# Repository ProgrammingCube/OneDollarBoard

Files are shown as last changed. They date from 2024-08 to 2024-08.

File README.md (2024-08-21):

# One Dollar Board

## What is it?
This ATtiny85 board is a bit different than most. In fact, it is a spiritual successor to the [One Dollar Board](https://www.indiegogo.com/projects/one-dollar-board--5/x/14830965#/updates/all) Indiegogo project from 2016. This campaign made more than its goal and failed to deliver. Now, I am much more experienced than I was then. This project is my attempt to bring its idea to fruition.

While I have no where the buisness connections to create a true $1 board, this kit is something you can [buy]() or print yourself!

## Build process

Watch the video (https://youtu.be/vt5fpE0bzSY)

This video will help you through the build process of the board. If you wish to have a writeup, [this]() is a link to the build how-to PDF. Those who purchase this kit will have also have a physical manual.

## Arduino IDE Setup
[Download Arduino IDE](https://www.arduino.cc/en/software)

In order to use this board seamlessly with the Arduino IDE, you need to install the Digispark Boards. These boards seem to be discontinued, but the json file is still extant.

Simply go to `File >> Preferencess` and click on the `Additional Boards Manager URLs` to add this entry:

`https://raw.githubusercontent.com/digistump/arduino-boards-index/master/package_digistump_index.json`

Click on OK.

Then, go `Tools >> Board... >> Boards Manager`. From here, search `Digistump`. Install the Digistump AVR Boards package. Accept any driver installs, we need these to talk to the boards because we are using a special bootloader.

#### Special note on the Bootloader***
Your ATtiny85 comes with a bootloader preinstalled, the [Micronucleus](https://github.com/SpenceKonde/ATTinyCore/blob/v2.0.0-devThis-is-the-head-submit-PRs-against-this/avr/extras/Ref_Micronucleus.md) bootloader. This allows one to program the chip via USB instead of using a middle-man ISP. You can still use an ISP if you want though, and its easy enough to flash back to the Micronucleus bootloader.

Here is the [link](https://github.com/ashishchoudhary9998/ATtiny85-Boot-loader) for the Micronucleus bootloader I have used. You can use a different one if you want, or if you're good enough, you can [make your own](https://ww1.microchip.com/downloads/aemDocuments/documents/MCU08/ApplicationNotes/ApplicationNotes/Basic-Bootloader-for-AVR-MCU-DA-Family-DS00003341C.pdf) or even [write it in C](https://github.com/m3y54m/simple-avr-bootloader) !

Once you have the board installed, select the correct board by doing `Tools >> Boards... >> Digistump AVR Boards >> Digispark (Default, 16.5mhz)`. Then select `Tools >> Programmer >> Micronucleus`.
**IF YOU CAN'T UPLOAD CODE AND YOU GET A MESSAGE WITH ONLY 60% UPLOADED, CHECK YOUR PROGRAMMER SELECTION** For some reason, Arduino IDE likes to deselect this.

## Microchip Studio Setup
[Download Microchip Studio](https://www.microchip.com/en-us/tools-resources/develop/microchip-studio#Downloads)

Setup is a bit more nuanced, and it can be a bit more difficult if your computer setup is different. However, the setup is almost the same!

Refer to the **Arduino IDE Setup** section and follow the guide to install the board in the Boards Manager. From there, we pick up.

To start a new project, you need to select what language you will use. From there, you need to add an `External Tool`.

`External Tools` is a fantastic feature in which you can run user-arbitrary executables with whatever command line options you want. Most uses exercise this feature to add custom binary upload programs to the IDE, making a seamless environment from code, compile, to upload.

Here's what to do. Go to `Tools >> External Tools...`. From there, click `Add`. Name the tool something meaningful, like `ATtiny85_VUSB` or `ATtiny85_Micronucleus` or something like that.

Next, we will fill out the `Command` field. This will specify which .exe to run when the External Tool is selected. For us, we need to use the `launcher.exe` supplied by the Arduino board install.

In order to find this tool, go to the Arduino IDE, go to `File >> Preferences` and enable `Show verbose output during` for `upload`. Then, select the Digistump board as in the **Arduino IDE Setup**, and build/upload a blank sketch to your ATtiny85 board.

In the `Output` window, you should see something like this:

`C:\Users\yourusername\AppData\Local\Arduino15\packages\digistump\tools\micronucleus\2.0a4/launcher.exe`

or wherever you have installed Arduino IDE. Copy this text to the `Command` field in the `External Tools...` window.

Next, you can copy this text directly to the `Arguments` field:

`-cdigispark --timeout 60 -Uflash:w:"$(TargetName)\$(TargetName)\Debug\$(TargetName).hex":i`

The variables `$(TargetNamee)` are used so the default .hex file will be uploaded, regardless of what the source file is named.

Next, we need to change the `Initial Directory` field. This directory will be the `Atmel Studio/7.0` folder's location like this:

`C:\Users\yourusername\Documents\Atmel Studio\7.0`

There's a strange bug in Microchip Studio in which spaces in the directory aren't handled right, so we'll do this to avoid problems.

Perfect! Now, when you use Microchip Studio, you can press `F7` to compile/assemble your program, then use `Tools >> your-external-tool` to upload! If you're good, you can [keybind your tool](https://onlinedocs.microchip.com/pr/GUID-ECD8A826-B1DA-44FC-BE0B-5A53418A47BD-en-US-12/index.html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)!
# FAQ
### The PWR LED doesn’t turn on!!!
- Check to make sure the power LED is installed the right way round. The molded flat plastic should be facing USER RIGHT.
- Double-check your USB connector solder joints. This LED is a direct power to ground connection, so if this doesn’t turn on, something simple is wrong.
- If your computer pops a message saying Overcurrent Detection, you may have a short in the upper-left quadrant of your board, or a short on the ATtiny85 IC socket. Ensure that all solder joints are isolated.
### The PB0 LED doesn’t blink!!!1!
Unfortunately, there can be many causes for this problem.
- Check if the LEDs are installed the right way round. The molded flat plastic should be facing USER RIGHT.
- Be sure that the ATtiny85 is installed correctly. Its index notch should be facing USER LEFT. Also, make sure its pins aren’t bent or sticking out from the socket.
- Double-check your soldering of the ATtiny85 IC socket. You wouldn’t believe how many times veteran hobbyists forget to solder entire chips!
### When I start using the other chips, nothing works!
- Check to see if there are shorts on the IC sockets.
- Check if the LD117V33 regulator is installed correctly. Refer to the images.
- Be careful on where you plug power and data cables. By design, this board is EXTREMELY flexible. I have tried to do my best to make the silkscreen clear, but it is still possible to accidentally switch around power and data pins. Refer to the pinout diagrams.

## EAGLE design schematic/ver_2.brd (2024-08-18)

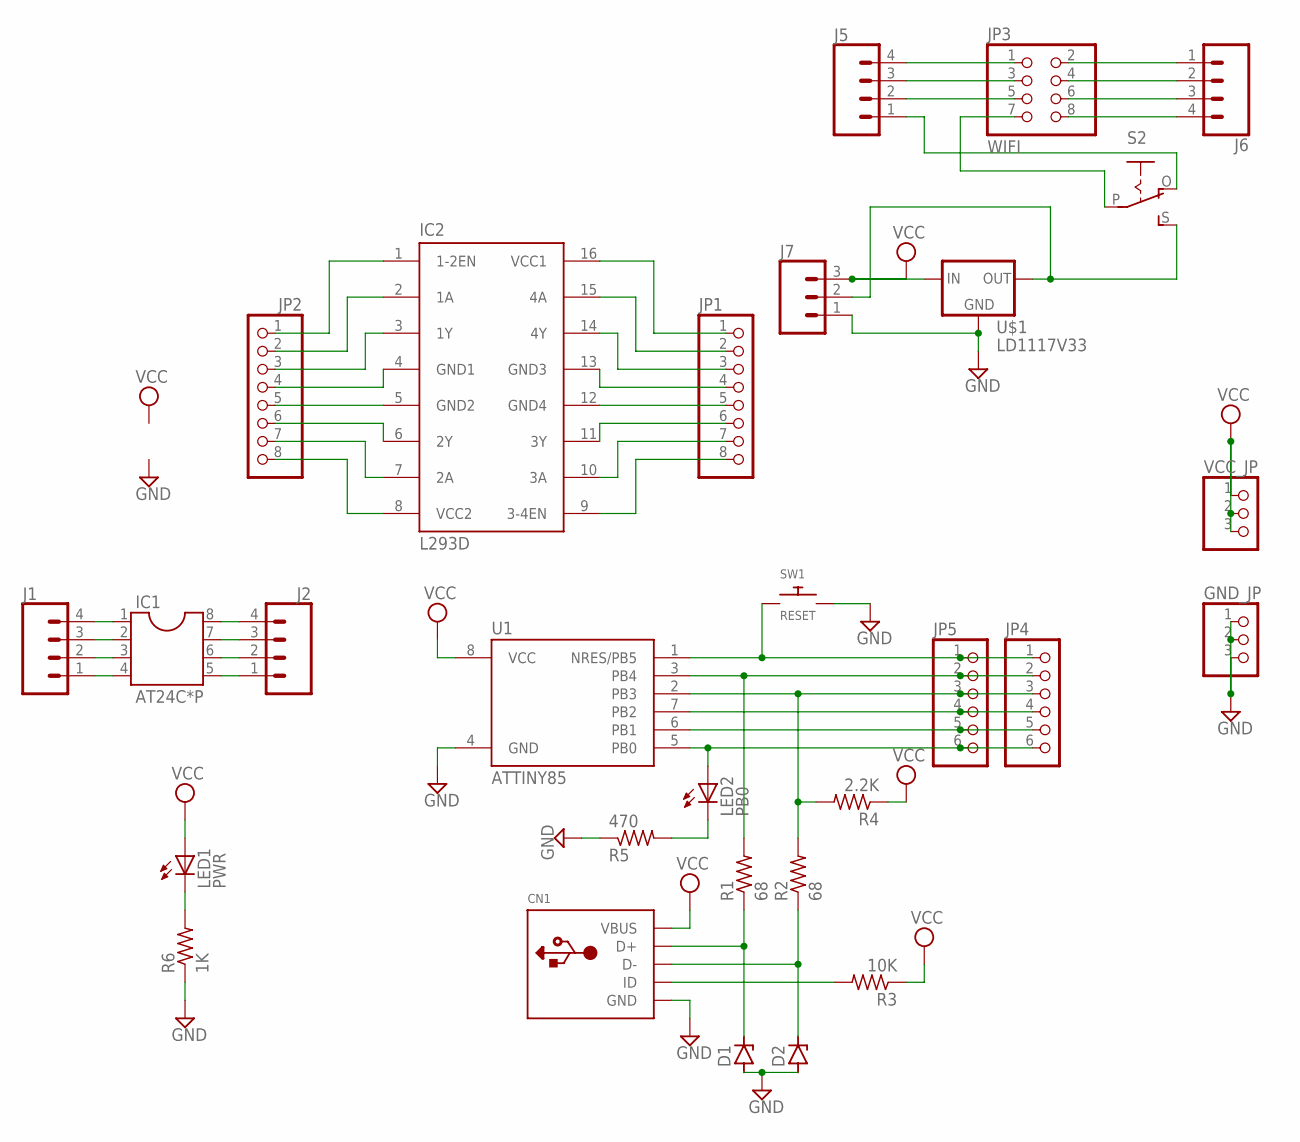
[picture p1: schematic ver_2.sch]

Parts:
CN1: USBTHM; USB-MINIB-THM
D1, D2: ZENER-DIODEDO34-7; DO34Z7
GND_JP: PINHD-1X3; 1X03
IC1: AT24C*P; SOCKET-08
IC2: L293D; DIL16
J1, J2: CONN_041X04_NO_SILK; 1X04_NO_SILK
J5, J6: CONN_04PTH; 1X04
J7: CONN_03; 1X03
JP1, JP2: PINHD-1X8CLEANBIG; 1X08-CLEANBIG
JP3: WIFI; 2X04
JP4, JP5: PINHD-1X6; 1X06
LED1: PWR; LED3MM
LED2: PB0; LED3MM
R1, R2: 68; 0204V
R3: 10K; 0204V
R4: 2.2K; 0204V
R5: 470; 0204V
R6: 1K; 0204V
S2: EG1218S; EG1218
SW1: RESET; TACT_PANA-EVQ
U1: ATTINY85; PDIP08_300MIL
U$1: LD1117V33
VCC_JP: PINHD-1X3; 1X03

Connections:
GND: CN1.GND, D1.A, D2.A, GND_JP.1, GND_JP.2, GND_JP.3, J7.1, R5.1, R6.1, SW1.P$2, U1.4 (GND), U$1.GND
unnamed: JP4.1, JP5.1, SW1.P$1, U1.1 (NRES/PB5)
unnamed: JP4.2, JP5.2, R1.2, U1.3 (PB4)
unnamed: JP4.3, JP5.3, R2.2, R4.2, U1.2 (PB3)
unnamed: JP4.4, JP5.4, U1.7 (PB2)
unnamed: JP4.5, JP5.5, U1.6 (PB1)
unnamed: JP4.6, JP5.6, LED2.A, U1.5 (PB0)
unnamed: IC1.4, J1.1
unnamed: IC1.3, J1.2
unnamed: IC1.2, J1.3
unnamed: IC1.1, J1.4
unnamed: IC1.5, J2.1
unnamed: IC1.6, J2.2
unnamed: IC1.7, J2.3
unnamed: IC1.8, J2.4
unnamed: CN1.ID, R3.2
unnamed: IC2.4 (GND1), JP2.4
unnamed: CN1.D+, D1.C, R1.1
unnamed: CN1.D-, D2.C, R2.1
unnamed: IC2.5 (GND2), JP2.5
unnamed: IC2.6 (2Y), JP2.6
unnamed: IC2.7 (2A), JP2.7
unnamed: IC2.8 (VCC2), JP2.8
unnamed: IC2.3 (1Y), JP2.3
unnamed: IC2.2 (1A), JP2.2
unnamed: IC2.1 (1-2EN), JP2.1
unnamed: J6.3, JP3.6
unnamed: J6.2, JP3.4
unnamed: JP3.7, S2.P
unnamed: J5.2, JP3.5
unnamed: J5.3, JP3.3
unnamed: J5.4, JP3.1
unnamed: J6.4, JP3.8
unnamed: J7.2, S2.S, U$1.OUT
unnamed: J6.1, JP3.2
unnamed: IC2.12 (GND4), JP1.5
unnamed: IC2.11 (3Y), JP1.6
unnamed: IC2.10 (3A), JP1.7
unnamed: IC2.9 (3-4EN), JP1.8
unnamed: IC2.13 (GND3), JP1.4
unnamed: IC2.14 (4Y), JP1.3
unnamed: IC2.15 (4A), JP1.2
unnamed: IC2.16 (VCC1), JP1.1
unnamed: LED2.K (C), R5.2
unnamed: LED1.K (C), R6.2
unnamed: J5.1, S2.O
VCC: CN1.VBUS, J7.3, LED1.A, R3.1, R4.1, U1.8 (VCC), U$1.IN, VCC_JP.1, VCC_JP.2, VCC_JP.3

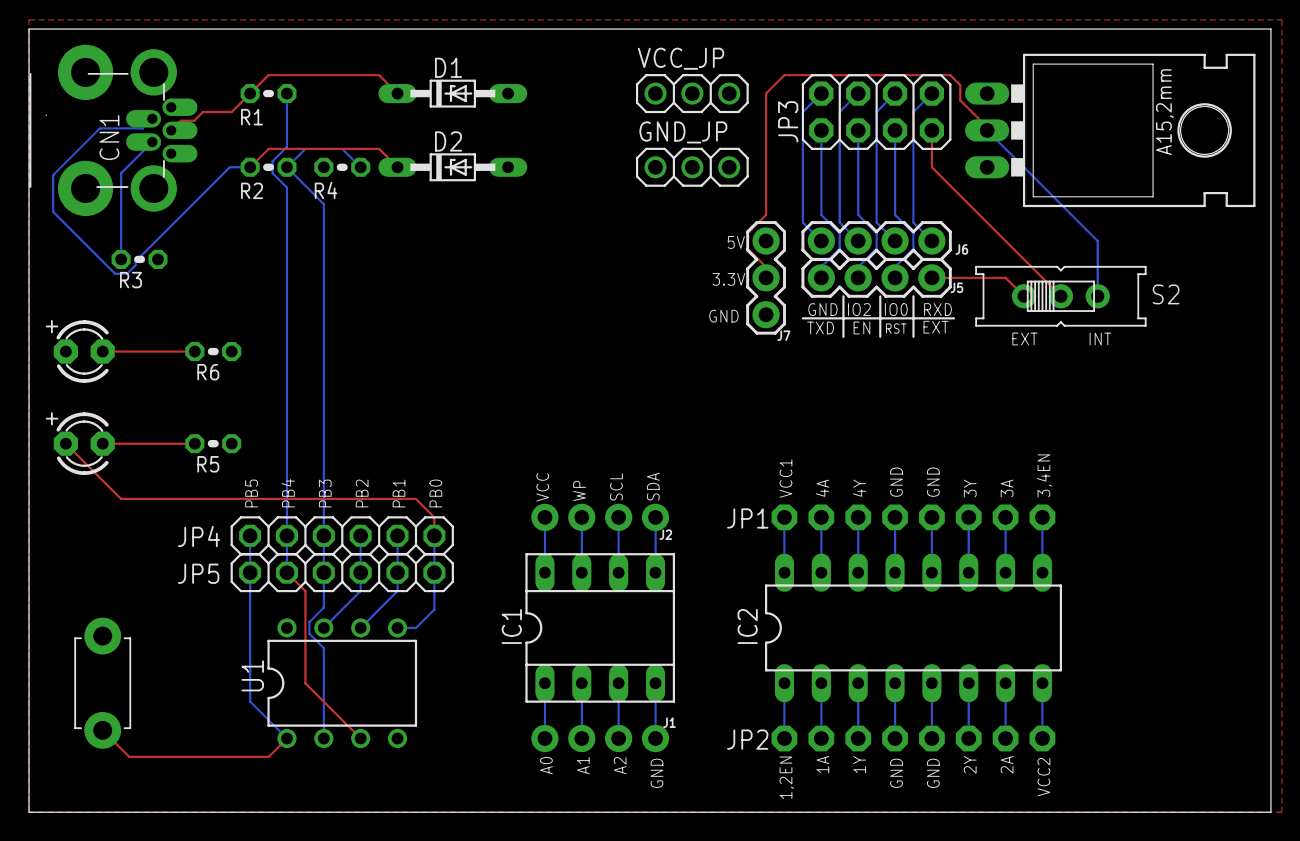
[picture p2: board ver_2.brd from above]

Board: 2 copper layers, 85.6 x 54.0 mm, 29 parts (0 on the bottom side), 47 nets.

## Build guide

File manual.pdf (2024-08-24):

# One Dollar Board

### Standalone ATtiny85 Development Kit

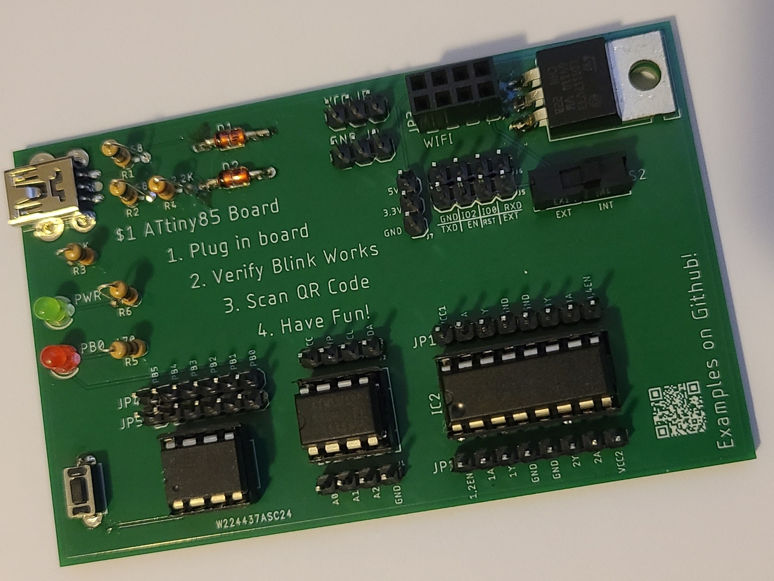
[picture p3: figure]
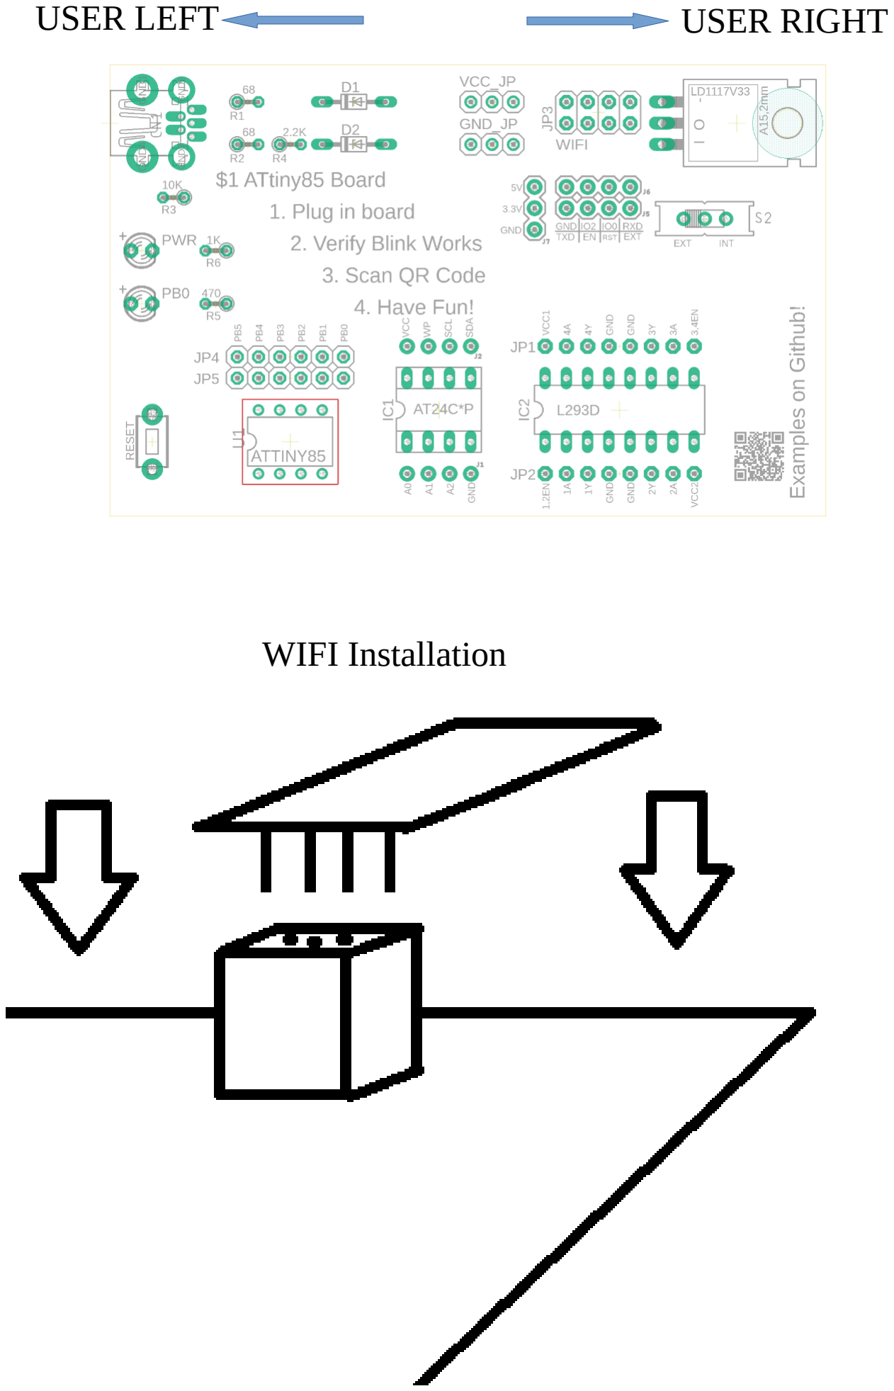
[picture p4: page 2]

USER LEFT | USER RIGHT

WIFI Installation

## Bill of Materials

(1) PCB
(2) 8 pin IC socket
(1) 16 pin IC socket
(1) ATtiny85
(1) AT24C16D
(1) L293D
(1) Red LED
(1) Green LED
(1) USB Micro Female
(2) 3.6v Zener diode
(1) LD117V33
(1) Push Button Switch
(1) 3 Pole Slide Switch
(2) 2.54 Header Male
(1) 2.54 2x4 Header Female
(2) 68 ohm Resistor
(1) 2.2 kohm Resistor
(1) 1 kohm Resistor
(1) 10 kohm Resistor
(1) 470 kohm Resistor

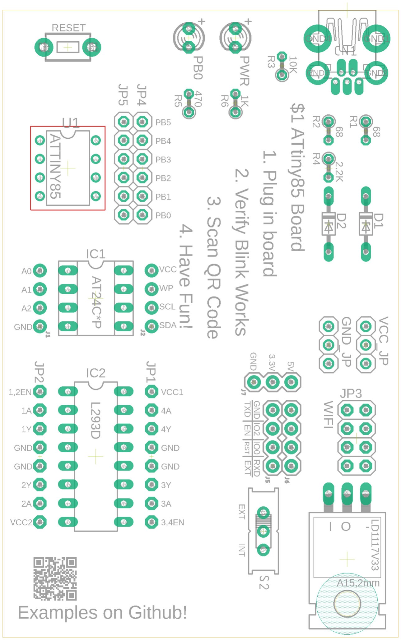
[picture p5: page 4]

This kit requires basic soldering skills and equipment!

### 1. Start by soldering in the three (3) IC sockets. Be sure to have

the index notch pointed USER LEFT!! I find the easiest way to solder these is to place them on the board, then flip the board over. Solder one (1) corner pin on each socket. Next, holding the board with your non-soldering iron hand, place your index finger (AVOID THE CORNER PIN AREA) on each socket one at a time while heating up that socket's soldered pin slightly. This will align the socket just right. Finish this step by flipping the board upside down again and finish off the soldering for the sockets.

### 2. Solder the resistors. To install these, take one lead and bend it

around until it is pointing the same direction as the other lead, like a lowercase 'n'. There is no wrong way to install these resistors, as they have no polarity. However, I do like to install the resistors with the resistor package resting on the circle of its silkscreen.

### 3. Bend and install the Zener diodes. To do this, use your

thumbnail and index finger to bend the leads about 3mm out from the package and down into a right angle. You should not be bending the leads right up against the package, or you will find installation difficult.

### 4. Install the power and GPIO LEDs. Take careful note of the

leads. The longer lead is the positive lead, and the negative side of the LED will also be molded slightly flat like the silkscreen shows. Keep in mind that LEDs are fairly delicate, so do not linger on a lead for more than 2 seconds with the iron.

### 5. Install the voltage regulator. I find that by taking a small pair

of needle nose pliers, one can bend the leads around 45-50 degrees to the component package. Then, you can easily slide the regulator into its holes. Look at the finished board picture for a visual. Line up the screw hole with the hole in the PCB before soldering in.

### 6. Solder in the headers. I find that the easiest way to do this is

similar to the sockets. Solder one end pin of a header into place, then use your index finger to press the header flush against the board as you reheat the solder joint. Once aligned, go back and solder the rest of the header pins.

### 7. Solder in the switches. The RESET switch should snap in place

and you can even solder this component without flipping the board over. Soldering the 2 position switch should be like the headers; solder one pin, press to align, and reheat the joint.

### 8. Install the micro-USB port. Place this gently on the footprint

and fill one of the four (4) ground contacts with solder. You will now be able to flip the board around and finish the soldering of this component. Keep in mind that the data pins will barely poke through the circuit board when aligned properly. Finish soldering the three (3) ground contacts.

Install the chips!
Slightly bend the package pins of the ICs inward to perpendicular with the surface of the package. I do this by taking the chip on its side and gently pressing it against a table or book. Be sure the index notch is facing USER LEFT when the chip is installed into its socket. Be sure no pins are being bent or twisted, go slow!

Plug in the board. The onboard micronucleus firmware should start the bootloader, and after 8 seconds the pin 0 LED should blink!

Let’s head over to the Git to set up your drivers and IDE!

https://github.com/ProgrammingCube/OneDollarBoard

Powering the ESP-01 Wifi Board

The slide switch on the board next to the ESP module controls where the power comes from. Because the wifi module is powered by 3.3 volts instead of the USB 5 volts, you can slide the switch to the RIGHT, to the INT position. This uses the on-board voltage regulator to power the board.
If you have the switch slid to the LEFT, to the EXT position, power will be taken in by the EXT pin on the header. You will need to supply your own power into the board. This is handy if you are taxing your USB power supply.

RESET Circuit

The RESET circuit is extremely simple on this board. The RESET push button switch simply pulls PB0 of the ATtiny85 down to GND. There is no debounce nor a pulldown/pullup. If you search other schematics, like the Digispark board, there is a pullup to power on the reset line. I have found that a board this simple does not need a pullup.
When pressed, the Micronucleus bootloader will enter the bootloader for 8 seconds. In this state, it can respond to data on the USB connected lines. This is when you need to upload your code. By using the launcher.exe provided by the Arduino board library, you will be prompted to plug in your board during upload. It is at this time you should press the RESET button, as it is much simpler than unplugging/replugging your board.
The RESET pin is not connected to any other chip on this board.

ISP (In System Programming)

If you need to reflash the Micronucleus bootloader or desire to use an ISP, you can use an Arduino as an ISP!

Disconnect the USB from the ATtiny85 board. You will now power this board from an Arduino Uno or equivalent. Please connect the pins like so:

Arduino--> ATtiny85

5V | Vcc
GND | GND
Pin 13 | PB2
Pin 12 | PB1
Pin 11 | PB0
Pin 10 | PB5/Reset
From here, use the Arduino IDE to flash the ArduinoISP sketch to your Arduino. From here, connect an electrolytic capacitor (10-22uF) between GND and RESET. This prevents the ArduinoISP device from resetting before it can write code to your ATtiny95 board.
From here, choose the Digistump 16.5mhz default board option as the target, and instead of uploading code via the normal Upload button, you need to choose Ctrl-Shift-U or Sketch >> Upload Using Programmer… You need to also have the ArduinoISP programmer selected under Tools >> Programmer. Make sure your COM port is also selected correctly to your Arduino.

Using an ISP instead of the Micronucleus bootloader will allow you to use the full 8192 bytes of flash memory, instead of the Micronucleus’s ~6.3kb.

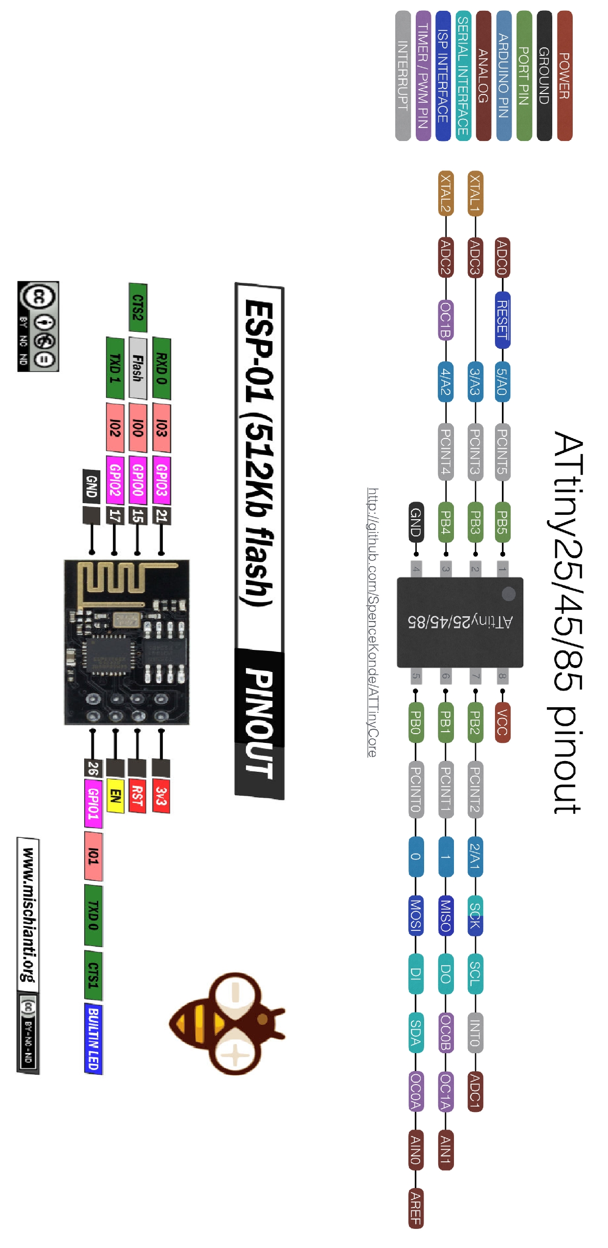
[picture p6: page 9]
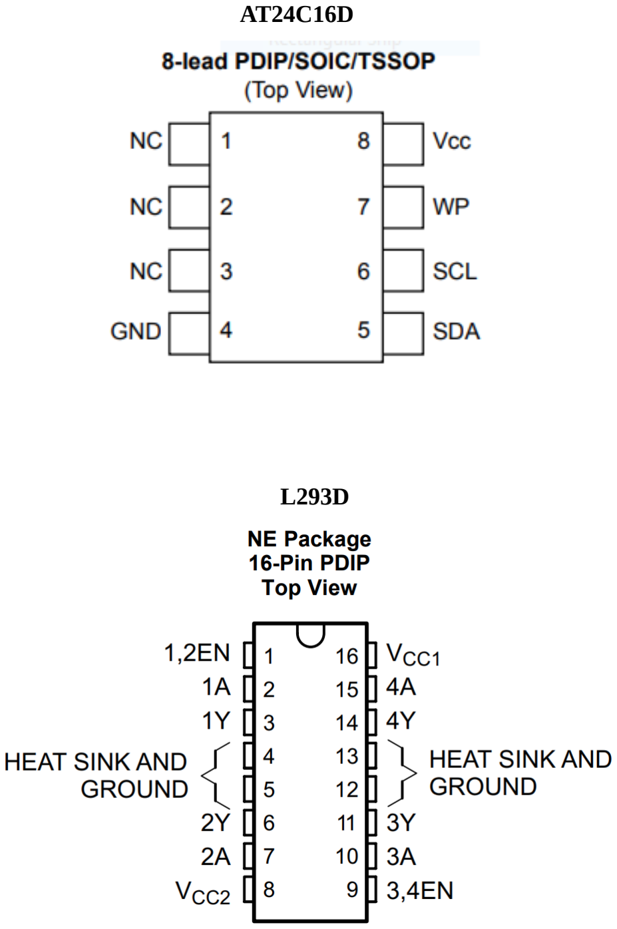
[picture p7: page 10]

AT24C16D

L293D

## FAQ

-The PWR LED doesn’t turn on!!!
- Check to make sure the power LED is installed the right way round. The molded flat plastic should be facing USER RIGHT.
- Double-check your USB connector solder joints. This LED is a direct power to ground connection, so if this doesn’t turn on, something simple is wrong.
- If your computer pops a message saying Overcurrent Detection, you may have a short in the upper-left quadrant of your board, or a short on the ATtiny85 IC socket. Ensure that all solder joints are isolated.

-The PB0 LED doesn’t blink!!!1!
Unfortunately, there can be many causes for this problem.
- Check if the LEDs are installed the right way round. The molded flat plastic should be facing USER RIGHT.
- Be sure that the ATtiny85 is installed correctly. Its index notch should be facing USER LEFT. Also, make sure its pins aren’t bent or sticking out from the socket.
- Double-check your soldering of the ATtiny85 IC socket. You wouldn’t believe how many times veteran hobbyists forget to solder entire chips!

-When I start using the other chips, nothing works!
- Check to see if there are shorts on the IC sockets.
- Check if the LD117V33 regulator is installed correctly. Refer to the images.
- Be careful on where you plug power and data cables. By design, this board is EXTREMELY flexible. I have tried to do my best to make the silkscreen clear, but it is still possible to accidentally switch around power and data pins. Refer to the pinout diagrams.

Patrick Jackson
2024

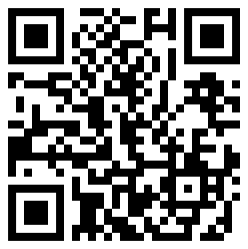
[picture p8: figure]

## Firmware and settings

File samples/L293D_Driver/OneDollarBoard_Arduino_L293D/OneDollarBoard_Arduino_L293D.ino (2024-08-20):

//L293D
//Motor A
const int motorPin1  = 0;  // Pin 14 of L293
const int motorPin2  = 1;  // Pin 10 of L293
//Motor B
const int motorPin3  = 2; // Pin  7 of L293
const int motorPin4  = 3;  // Pin  2 of L293

//This will run only one time.
void setup()
{
    //Set pins as outputs
    pinMode(motorPin1, OUTPUT);
    pinMode(motorPin2, OUTPUT);
    pinMode(motorPin3, OUTPUT);
    pinMode(motorPin4, OUTPUT);
    
    //Motor Control - Motor A: motorPin1,motorpin2 & Motor B: motorpin3,motorpin4

    //This code  will turn Motor A clockwise for 2 sec.
    digitalWrite(motorPin1, HIGH);
    digitalWrite(motorPin2, LOW);
    digitalWrite(motorPin3, LOW);
    digitalWrite(motorPin4, LOW);
    delay(2000); 
    //This code will turn Motor A counter-clockwise for 2 sec.
    digitalWrite(motorPin1, LOW);
    digitalWrite(motorPin2, HIGH);
    digitalWrite(motorPin3, LOW);
    digitalWrite(motorPin4, LOW);
    delay(2000);
    
    //This code will turn Motor B clockwise for 2 sec.
    digitalWrite(motorPin1, LOW);
    digitalWrite(motorPin2, LOW);
    digitalWrite(motorPin3, HIGH);
    digitalWrite(motorPin4, LOW);
    delay(2000); 
    //This code will turn Motor B counter-clockwise for 2 sec.
    digitalWrite(motorPin1, LOW);
    digitalWrite(motorPin2, LOW);
    digitalWrite(motorPin3, LOW);
    digitalWrite(motorPin4, HIGH);
    delay(2000);    
    
    //And this code will stop motors
    digitalWrite(motorPin1, LOW);
    digitalWrite(motorPin2, LOW);
    digitalWrite(motorPin3, LOW);
    digitalWrite(motorPin4, LOW);
}


void loop() {}

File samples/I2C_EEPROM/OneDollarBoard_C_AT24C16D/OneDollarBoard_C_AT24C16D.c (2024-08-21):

/*
 * ATtiny85_I2C_Eeprom_C.c
 *
 * Created: 7/27/2024 4:36:07 PM
 * Author : Patrick
 */ 

#ifndef F_CPU
#define F_CPU	16500000UL				// 16.5MHz clock speed
#endif

#include <avr/io.h>
#include <util/delay.h>
#include <string.h>
#include "inc/USI_TWI_Master.h"

#define	delay(x)	_delay_ms(x)

#define I2C_READ	TRUE<<TWI_READ_BIT
#define I2C_WRITE	FALSE<<TWI_READ_BIT

#define	MEMORY_ADDR_HEADER	0b1010
#define MEMORY_ADDR_ADDR	0b0000
#define MEMORY_I2C_ADDR		(MEMORY_ADDR_HEADER<<3)|(MEMORY_ADDR_ADDR)

typedef uint8_t byte;

/* main function */
int main( void )
{
	
	byte page_to_write[] = { ( byte ) ( MEMORY_I2C_ADDR << TWI_ADR_BITS ) | I2C_WRITE,
							 0x0, 0x1, 0x2, 0x3, 0x4, 0x5, 0x6, 0x7,
							 0x8, 0x9, 0xA, 0xB, 0xC, 0xD, 0xE, 0xF };
	
    /* set up USI block as I2C */
	USI_TWI_Master_Initialise();
	
	/* write page to see if this actually does anything at all */
	( void ) USI_TWI_Start_Read_Write( page_to_write, 17 );
	
	/* clear buffer to see if the read works */
	memset( page_to_write, 0, 17 );
	
	/* set first byte of page to memory IC address as a read address */
	page_to_write[ 0 ] = ( byte ) ( MEMORY_I2C_ADDR << TWI_ADR_BITS ) | I2C_READ;
	
	/* send page to be read */
	( void ) USI_TWI_Start_Read_Write( page_to_write, 17 );
	
    while (1) 
    {
    }
}

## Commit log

2024-08-18 first samples push
2024-08-18 schematic push
    [ver_2.brd, ver_2.sch]
2024-08-19 arduino EEPROM example update
2024-08-20 samples doc fix
2024-08-21 l293d c sample push

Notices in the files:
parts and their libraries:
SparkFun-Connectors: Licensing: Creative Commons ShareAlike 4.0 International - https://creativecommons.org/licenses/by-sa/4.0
